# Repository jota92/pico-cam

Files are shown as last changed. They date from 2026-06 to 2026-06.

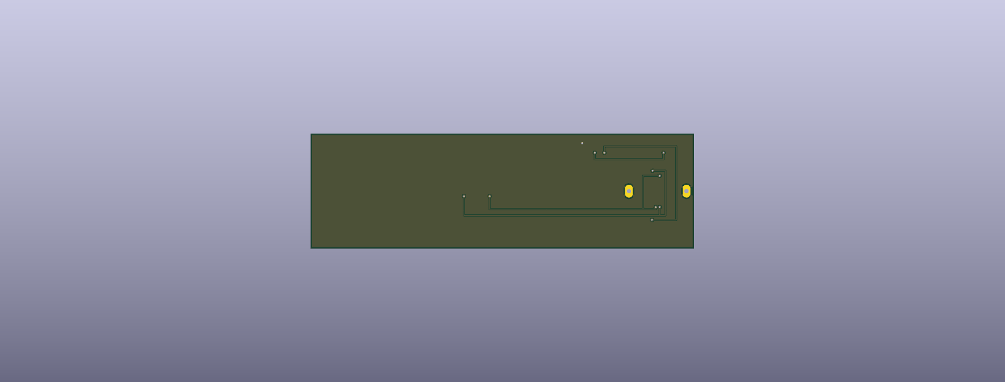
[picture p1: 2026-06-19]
pico-cam-latest/device_kicad/CameraIoT_USB-C_Programmer_Dock_bottom.png

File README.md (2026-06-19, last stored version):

# Pico-Cam (Camera IoT)

ESP32-S3 (ESP32-S3-PICO-1-N8R8) をベースにした、超小型・低消費電力の IoT カメラプロジェクトです。ディープスリープを活用し、定期的に JPEG 画像を撮影して Wi-Fi 経由でサーバーにアップロードします。

本リポジトリには、デバイス基板、書き込み・充電用のドック基板の KiCad 回路図・レイアウトデータ、PlatformIO 用のファームウェア、およびアップロード受信用サーバーのサンプルコードが含まれています。

---

## プロジェクト構成

```text
pico-cam/
├── camera_iot/                 # メインの開発・製造パッケージ
│   ├── device_kicad/           # デバイス本体の基板データ (38x18mm 版)
│   ├── cradle_kicad/           # 充電・書き込み用クレードル基板データ (RevA)
│   ├── mechanical/             # デバイスおよびクレードルのレイアウト画像・図面
│   ├── firmware_platformio/    # ESP32-S3 ファームウェア (PlatformIO)
│   ├── server_example/         # アップロード受信用 Express.js サーバー
│   ├── docs/                   # ピンマップや電気設計メモ、DRC レポートなどの設計文書
│   ├── scripts/                # 基板生成や監査用の各種 Python スクリプト
│   ├── jlcpcb_38x18/           # 38x18mm 版の製造用 Gerber/BOM/CPL 出力
│   └── jlcpcb_dock/            # ドック基板の製造用 Gerber/BOM/CPL 出力
├── device_kicad_friend/        # 代替・改良版の基板データ
│   ├── CameraIoT_RevF_40x20_ThroughVia_FINAL.kicad_pcb  # RevF 本体基板 (40x20mm、ブラインドビアなしの通常の4層)
│   ├── CameraIoT_USB-C_Programmer_Dock.kicad_pcb        # USB-C プログラマードック基板
│   └── README_HANDOFF.md       # RevF 基板の製造仕様・引き継ぎドキュメント
├── KiCad/                      # 実行環境用の KiCad 設定 / プロファイル
├── .kicad_cli_profile/         # KiCad CLI 用プロファイル
├── freerouting-1.9.0.jar       # 基板配線用オートルーター (FreeRouting)
└── README.md                   # 本ドキュメント
```

---

## ハードウェア仕様

本プロジェクトには、用途や製造コストに合わせて 2 つの基板バリエーションが存在します。

### 1. デバイス本体基板

*   **ESP32-S3-PICO-1-N8R8**: 8MB Quad Flash & 8MB Octal PSRAM 内蔵モジュール
*   **インターフェース**: カメラモジュール (OV2640 等)、充電検出、ステータス LED、操作ボタン
*   **電源**: LiPo バッテリー接続用コネクタ (J2: JST SH 2ピン)

#### バリエーション:
1.  **38x18mm 版 (`camera_iot/device_kicad/`)**:
    *   極小サイズの設計。
    *   製造用データは `camera_iot/jlcpcb_38x18/` にあります。
2.  **40x20mm RevF 版 (`device_kicad_friend/`)**:
    *   ブラインドビア/埋め込みビアを排除し、通常の「4層貫通ビア (Through-Via)」のみで配線した設計。
    *   JLCPCB などの一般的な基板メーカーで安価に製造可能。
    *   外形寸法: 40.0 x 20.0 mm、基板厚: 0.8 mm。

### 2. 充電・書き込み用ドック (クレードル)

デバイス本体には USB コネクタを搭載せず、外部ドック（ポゴピンまたはケーブル接続）を介して充電やファームウェア書き込みを行います。

*   **Pogo ピンまたは 6-Pin ケーブルインターフェース**:
    1.  `VBUS / VCHG_5V` (電源)
    2.  `GND` (グランド)
    3.  `USB_D+` (native USB D+ / GPIO20)
    4.  `USB_D-` (native USB D- / GPIO19)
    5.  `GPIO0 / BOOT` (書き込みモード遷移用)
    6.  `CHIP_PU / RESET` (チップリセット)
    *   (RevC の pogo 設計では、STAT / WAKE_ID を含めた 8 ポゴピン仕様も存在)

---

## ファームウェア (PlatformIO)

`camera_iot/firmware_platformio/` に格納されているファームウェアは、ESP32-S3 の native USB 機能と Wi-Fi 機能、省電力制御を実装しています。

### ピンアサイン (Pin Map)
*   **PSRAM 競合回避**: ESP32-S3-PICO-1-N8R8 は Octal PSRAM のために `GPIO33~37` を占有するため、カメラのデータラインを `GPIO10-14`、`GPIO38-40` にマッピングして競合を回避しています。
*   **主要ピン**:
    *   `PWDN_GPIO_NUM`: GPIO21
    *   `RESET_GPIO_NUM`: GPIO18
    *   `XCLK_GPIO_NUM`: GPIO15
    *   `SIOD_GPIO_NUM` (SDA): GPIO8
    *   `SIOC_GPIO_NUM` (SCL): GPIO9
    *   `Y2 ~ Y9` (カメラデータ D2~D9): GPIO40, 39, 38, 14, 13, 12, 11, 10
    *   `VSYNC_GPIO_NUM`: GPIO16
    *   `HREF_GPIO_NUM`: GPIO17
    *   `PCLK_GPIO_NUM`: GPIO41
    *   `LED_STATUS_GPIO`: GPIO47 (ステータス LED)
    *   `CHG_DETECT_GPIO`: GPIO4 (充電検出ピン、分圧経由)
    *   `WAKE_BUTTON_GPIO`: GPIO5 (操作・スリープ解除ボタン)
    *   `WAKE_ID_GPIO`: GPIO1 (クレードル接続識別)
    *   `USB_DN_GPIO / USB_DP_GPIO`: GPIO19 / GPIO20 (Native USB デバッグ・書き込み用)

### 主な動作フロー:
1.  **起動**: スリープまたは電源 ON で起動。
2.  **充電検出**: `CHG_DETECT_GPIO` が HIGH の場合（ドックで充電中など）、不要なカメラ撮影や Wi-Fi 接続を行わず、充電に専念するために即座に 1 分間のディープスリープに入ります。
3.  **撮影**: カメラを初期化し、JPEG 画像を取得して PSRAM に格納。
4.  **Wi-Fi 送信**: Wi-Fi に接続し、指定された HTTP サーバへ POST リクエストで画像を送信。
5.  **休止**: 送信完了（またはタイムアウト/エラー）後、ステータス LED をパターン点滅させ、10 分間のディープスリープに入ります。

---

## サーバー (server_example)

`camera_iot/server_example/` は Node.js (Express.js) で書かれたシンプルなアップロード受付サーバーです。

*   **動作**: 送信されてきた Raw JPEG データをトークン認証の上で受信し、日時とランダム文字列のファイル名（例: `2026-06-20T01-23-57-123Z-abcd1234.jpg`）で `./uploads` ディレクトリに保存します。
*   **起動方法**:
    ```bash
    cd camera_iot/server_example
    npm install
    # トークンやポートを指定して起動
    PORT=3000 DEVICE_TOKEN="your-secret-token" node server.js
    ```

---

## 開発と製造に関する注意点

*   **BOM の手配**: LCSC などの自動 PCBA を利用する場合、カメラコネクタや一部の IC など、手作業でのマウント (PCBA 後の手半田) が必要な部品が存在します。詳細は `camera_iot/docs/manual_procurement_revC.md` や `device_kicad_friend/README_HANDOFF.md` をご確認ください。
*   **DRC（デザインルールチェック）**:
    *   RevF 基板は KiCad 10.0.1 の DRC にて、重大なエラー・未配線ともに 0 件であることを確認済みです。

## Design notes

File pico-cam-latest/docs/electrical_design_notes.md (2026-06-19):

# Electrical Design Notes

## Current architecture

- Device board: `40 x 20 mm`, 4-layer, `0.8 mm`
- Dock board: USB-C to 6-wire cable dock, 2-layer, `1.0 mm`
- No pogo pins
- Device charging/programming connector:
  - `J3 = JST SH SM06B-SRSS-TB(LF)(SN) / C160405`
- Battery connector:
  - `J2 = JST SH SM02B-SRSS-TB(LF)(SN) / C160402`

## 6-wire cable pinout

1. `VCHG_5V`
2. `GND`
3. `USB_D+`
4. `USB_D-`
5. `GPIO0`
6. `CHIP_PU`

## Device behavior assumptions

- Charging input is detected by `CHG_DETECT` divider on `GPIO4`
- User button is on `GPIO5`
- Status LED is on `GPIO47`
- Native USB uses `GPIO19/GPIO20`
- `GPIO0` and `CHIP_PU` are exported only to the dock connector for flashing/reset

## Stock-driven substitutions applied

- `R1` charge-program resistor: `20k -> 21k`
- `R2/R9` divider and button pull-up: `100k -> 110k`
- `R4/R5/R6/R7`: `10k -> 12.4k`
- `R10`: `33R -> 30.1R`
- `R3/R11/R12/L2`: moved to `RTT029310FTH / C11715`
- Cradle CC resistors: `5.1k -> 5.11k`
- Removed cradle LEDs and their resistors
- Removed large 47uF output capacitor; output bulk now relies on distributed 10uF network already placed around `3V3`

## Known procurement caveats

- `U1`, `U5`, `LED1` are not closed by the current LCSC-only BOM and remain consign/global-sourcing candidates
- All other changed JST and passive parts were selected from currently in-stock LCSC alternatives during this revision

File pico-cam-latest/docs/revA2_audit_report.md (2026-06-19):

# CameraIoT RevA2 correction report

This package fixes the RevA1 fatal inconsistencies.

## Fixed

- ESP32-S3-PICO-1-N8R8 U1 pad net assignment now follows the Espressif package pin numbers.
- Camera D9-D5 are assigned to GPIO10-GPIO14 / U1 pads 15-19.
- U1 pads 38-42, which correspond to GPIO33-GPIO37, are left unconnected because they are used by the N8R8 octal PSRAM.
- CAM_D2 is no longer connected to U1 pad46. U1 pad46 is now 3V3 because it is VDD3P3_CPU.
- U1 pads55/56 are now 3V3 because they are VDDA. They were incorrectly tied to GND in the previous placeholder footprint.
- UART programming pins are now U1 pad49/U0TXD and U1 pad50/U0RXD.
- LED_STATUS is now GPIO47 / U1 pad37.
- Device and cradle pogo pitch remains 4.0 mm: 5V/GND/STAT/WAKE.
- Power, charger, LDO, RF matching, pullups, divider, LED, and passives now have explicit nets.

## Important remaining manufacturing note

This package corrects pad/net assignment. It still must be opened in KiCad and fully routed, DRC/ERC checked, and exported to Gerber before JLCPCB ordering. Do not upload the KiCad PCB directly as a finished production design without routing/DRC.

## Files added

- docs/device_pad_net_assignment_revA2.csv
- docs/cradle_pad_net_assignment_revA2.csv
- docs/revA2_audit_report.md
- docs/revA2_validation_report.txt

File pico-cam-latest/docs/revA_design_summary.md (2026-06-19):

# RevA1 design summary

Smallest version that still has a reasonable chance to boot, capture JPEG, send via Wi-Fi, and
charge via pogo pins. RevA1 applies the design-review fixes listed in FIXES_RevA1.md.

## What changed from earlier concept

- Camera DOVDD is 2.8 V (not 3.3 V) to match OV2640FSL typical module design.
- Added 2.8 V and 1.3 V LDOs; the camera cannot be powered from 3.3 V only.
- Added bottom programming pads because the final body has no USB-C.
- Battery is bottom-side adhesive/manual assembly, not JLC SMT.
- Antenna is fully inside the 40 x 20 mm outline, chip antenna + keepout.

## RevA1 fixes (key)

- Camera D9..D5 moved off GPIO33-37 (octal-PSRAM pins) -> GPIO10..14.
- Device charge-pad pitch set to 4.0 mm to match the cradle pogo pitch.
- 5V-detect divider re-ratioed (68k/100k -> ~3.0 V) off the logic threshold.
- GND reference zones + narrowed antenna keepout for RF.
- Added ESP32 local decoupling (0.1 uF x2 + 10 uF).
- Battery spec changed to PROTECTED cell; battery area cleared from antenna keepout.
- Cradle gets the charge LED (driven by STAT); redundant device charge LED removed.
- firmware memory_type corrected to qio_opi for N8R8.

## Remaining one-shot risk areas (verify before order)

- ESP32-S3-PICO-1 LGA56 land pattern + pin-1 must be rebuilt from the official Espressif
  drawing. The placeholder footprint's pad-to-function mapping is NOT the real pinout.
- OV2640 FPC connector orientation/contact side must be verified with a real camera module.
- RF match is not guaranteed until VNA tuning in the real case.
- Z-stack: camera (top) over battery (bottom) can reach ~11.85 mm if they overlap in XY.
  Use a <=3.2 mm cell under the camera footprint, a local battery cutout, or push the camera
  fully into the corner so it does not sit over the battery.
- 401230 high-discharge PROTECTED cell; common 1C cells are not enough for Wi-Fi peaks.
- All LCSC/JLC part numbers must be filled before a PCBA order (left blank intentionally).

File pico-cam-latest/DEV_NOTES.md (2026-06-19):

# Camera IoT RevC fabrication package

2026-06-16 時点で、RevC の completed routed 版を再構築済みです。  
ただし、この環境では `kicad-cli pcb drc` が異常終了するため、
最終確認は `導通監査 + 局所電源/インターフェース検証 + Gerber再生成` で行っています。

同日付で、新仕様として以下も追加しています。

- 本体ボタン 1 個で `短押し撮影 / 3秒 BLE設定 / 10秒 初期化`
- ステータス LED
- BLE 初期設定前提の `WAKE_ID` 分離
- 充電・書き込みドック用の **8 pogo** (`VBUS/GND/D+/D-/BOOT/RESET/STAT/WAKE_ID`)
- ESP32-S3 native USB (`GPIO19/20`) を使うドック経由書き込み

旧 `RevA*` 一式は監査・修正履歴として残していますが、発注入力には使わないでください。

## 完成物

- デバイス基板: `production_revC/device/CameraIoT_RevC_routed.kicad_pcb`
- クレードル基板: `production_revC/cradle/USB_C_to_Pogo_Cradle_RevC_routed.kicad_pcb`
- JLCPCB 用データ:
  - `production_revC/jlcpcb/device_BOM_JLCPCB_RevC.csv`
  - `production_revC/jlcpcb/device_CPL_JLCPCB_RevC.csv`
  - `production_revC/jlcpcb/device_manual_post_pcba_parts_RevC.csv`
  - `production_revC/jlcpcb/cradle_BOM_JLCPCB_RevC.csv`
  - `production_revC/jlcpcb/cradle_CPL_JLCPCB_RevC.csv`
  - `production_revC/jlcpcb/cradle_manual_post_pcba_parts_RevC.csv`
- Gerber ZIP:
  - `production_revC/device/CameraIoT_RevC_Gerbers.zip`
  - `production_revC/cradle/USB_C_to_Pogo_Cradle_RevC_Gerbers.zip`

## 現在の状態

- デバイス基板:
  - `scripts/build_device_revC_routed.py` で `CameraIoT_RevC_routed.kicad_pcb` を再生成可能
  - `scripts/check_revC_power_cell.py` は routed 完成版で `PASS`
  - `scripts/check_revC_interface_spec.py` は routed 完成版で `PASS`
  - `scripts/audit_connectivity.py` は routed 完成版で `unconnected_edges=0`
- クレードル基板:
  - 新仕様で USB2 D+/D- と 8 pogo、FLASH/RESET ボタンを追加
  - `scripts/audit_connectivity.py` では routed 完成版の `unconnected_edges=0` を確認済み
  - pogo は `Mill-Max 0906-0-15-20-75-14-11-0` を採用し、手実装前提で固定
- クレードルの手差しポゴピンは BOM から除外済み
- デバイスは `J2` LiPo SMT コネクタを追加済みで、電池リードの基板直半田は不要
- デバイスの底面接点とテストパッドは手作業項目として分離済み

## 発注時の注意

- `device_BOM_JLCPCB_RevC.csv` には LCSC 空欄が 9 行あります。これらは
  `JLC global sourcing/consigned` 前提です。
- カメラモジュール、電池、クレードルのポゴピンは PCBA 後の手組みです。
- 電池と pogo の固定品番は `docs/manual_procurement_revC.md` を見てください。
- KiCad 純正 DRC レポートだけは、この環境で `kicad-cli` が exit 134 になるため未取得です。

## 生成スクリプト

- RevC 生成元: `scripts/generate_revC.py`
- routed device 再構築: `scripts/build_device_revC_routed.py`
- 局所検証: `scripts/check_revC_power_cell.py`
- I/O仕様検証: `scripts/check_revC_interface_spec.py`
- 導通監査: `scripts/audit_connectivity.py`
- fabrication 出力再生成: `scripts/export_revC_fab.py`
- 旧 routed 基板局所修復: `scripts/repair_revC_routed_board.py`

KiCad 付属 Python で再生成する場合:

```bash
HOME=/tmp/kicad-home KICAD_CONFIG_HOME=/tmp/kicad-config \
/tmp/KiCad.app/Contents/Frameworks/Python.framework/Versions/3.9/bin/python3 \
scripts/generate_revC.py
```

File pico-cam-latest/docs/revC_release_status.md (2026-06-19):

# RevC Release Status

最終更新: 2026-06-17

## 結論

RevC は `pogo` を廃止し、6線 JST-SH ケーブル経由の USB-C ドック構成へ更新済みです。

- 本体: `production_revC/device/CameraIoT_RevC_routed.kicad_pcb`
- ドック: `production_revC/cradle/USB_C_to_Cable_Dock_RevC_routed.kicad_pcb`
- Gerber:
  - `production_revC/device/CameraIoT_RevC_Gerbers.zip`
  - `production_revC/cradle/USB_C_to_Cable_Dock_RevC_Gerbers.zip`

## 確認済み

- `scripts/check_revC_interface_spec.py`:
  - 6線ケーブル割当 `VCHG_5V / GND / USB_D+ / USB_D- / GPIO0 / CHIP_PU` を確認
- `scripts/audit_connectivity.py`:
  - device routed: `split_nets none`
  - cradle routed: `split_nets none`
- TPS63031 ピン割当は修正済み
- バッテリコネクタは LCSC 在庫ありの `SM02B-SRSS-TB(LF)(SN) / C160402` に変更済み
- ドック/本体ケーブルコネクタは `SM06B-SRSS-TB(LF)(SN) / C160405` に変更済み
- クレードル CC 抵抗は `5.11k / C25904` へ変更済み

## BOM 上の注意

以下は BOM 上で `consign` 扱いです。

- `U1` ESP32-S3-PICO-1-N8R8
- `U5` TLV70013DDCR
- `LED1` XL-1608UBC

つまり、**Gerber/BOM/CPL は生成済みだが、全点が LCSC 通常在庫だけで閉じているわけではありません。**
JLCPCB へはそのまま提出可能ですが、上記 3 点は JLC 側の実装可否確認または consign/global sourcing 前提です。

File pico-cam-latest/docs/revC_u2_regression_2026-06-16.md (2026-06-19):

# RevC U2 regression audit (2026-06-16)

## 要約

RevC デバイス基板は実際に配線済みで、既存 DRC レポートも `0 violations / 0 unconnected`
でした。  
ただし再監査で、`U2` TPS63031 のネット割当が生成スクリプトで回帰していることを確認しました。

これは **DRC では見抜けない論理結線ミス** です。  
したがって、既存の routed 基板と Gerber は現時点では発注不可です。

## 原因

`scripts/generate_revC.py` の旧実装:

```python
u2_nets = ["3V3", "SW2", "GND", "SW1", "VBAT", "VBAT", "GND", "VBAT", "GND", "3V3"]
```

この割当は TPS63031DSKR の正規 DSK ピン配置と一致しません。

正しい割当:

```python
u2_nets = ["SW1", "VBAT", "VBAT", "VBAT", "GND", "GND", "SW2", "3V3", "GND", "GND"]
```

## 影響

- `U2` 周辺の routed デバイス基板配線は、誤ったネット前提で成立している
- 既存 `production_revC/device/CameraIoT_RevC.kicad_pcb` は再ルーティングが必要
- 既存 Gerber / BOM / CPL / 発注用コピーは、そのまま使えない

## 補足

- `docs/recheck_2026-06-15_device_drc.txt`
- `docs/recheck_2026-06-15_cradle_drc.txt`

これらは RevC ではなく、旧 RevA 配置ファイルに対する再確認レポートです。
RevC の routed 基板評価と混同しないこと。

## 現在の対処

- 生成スクリプトの `U2` ネット割当は修正済み
- `U2` 周辺の固定配線と部品配置も修正済み
- `scripts/check_revC_power_cell.py` を追加し、以下をローカル再検証可能にした
  - `U2` pad1-11 のネット割当
  - `C4/C5/C7/C17/R8/R9/L1/U2` の局所配置
  - `SW1/SW2/VBAT/3V3` の固定配線
  - 電源セル局所クリアランス
- このチェッカーは `CameraIoT_RevC_unrouted.kicad_pcb` では通過し、
  既存 `CameraIoT_RevC.kicad_pcb` では失敗する
- `scripts/repair_revC_routed_board.py` で routed 基板の局所修復版
  `CameraIoT_RevC_repaired_local.kicad_pcb` を生成可能で、これも局所チェッカーを通過する
- ただし、修正後の routed デバイス基板は未再認定
- クレードル基板は今回の回帰の直接対象外

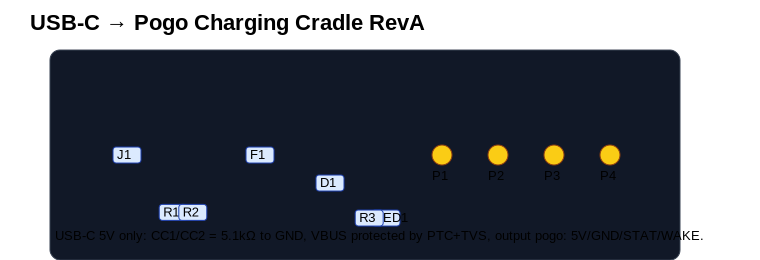
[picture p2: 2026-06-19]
pico-cam-latest/mechanical/cradle_layout_revA.png

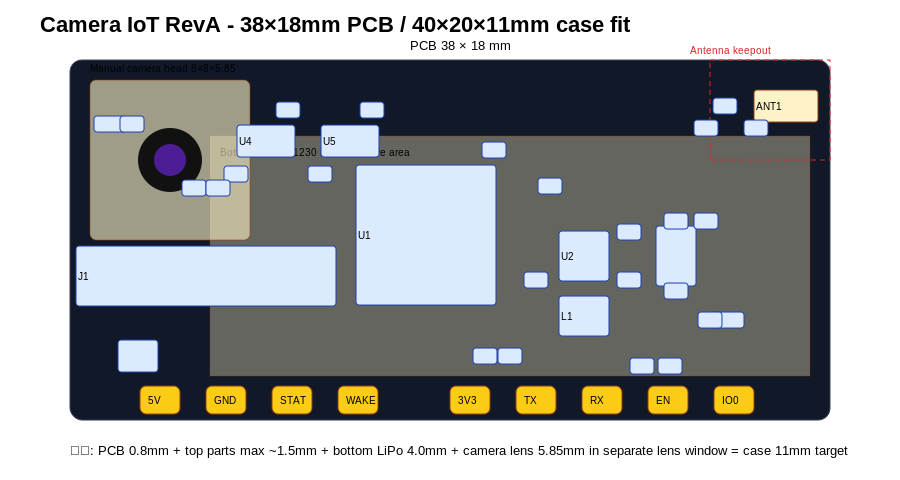
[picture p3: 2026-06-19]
pico-cam-latest/mechanical/device_layout_revA.png

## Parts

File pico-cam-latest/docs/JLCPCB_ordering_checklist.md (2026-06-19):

# JLCPCB Ordering Checklist

## 提出ファイル

本体:

1. `production_revC/device/CameraIoT_RevC_Gerbers.zip`
2. `production_revC/jlcpcb/device_BOM_JLCPCB_RevC.csv`
3. `production_revC/jlcpcb/device_CPL_JLCPCB_RevC.csv`

ドック:

1. `production_revC/cradle/USB_C_to_Cable_Dock_RevC_Gerbers.zip`
2. `production_revC/jlcpcb/cradle_BOM_JLCPCB_RevC.csv`
3. `production_revC/jlcpcb/cradle_CPL_JLCPCB_RevC.csv`

補助:

- `production_revC/jlcpcb/device_manual_post_pcba_parts_RevC.csv`
- `production_revC/jlcpcb/cradle_manual_post_pcba_parts_RevC.csv`

## 実装前提

- 本体は 4 層 0.8 mm
- ドックは 2 層 1.0 mm
- pogo は廃止済み
- 本体とドックの接続は `JST SH 6-pin (SM06B-SRSS-TB)` ケーブル

## ドック配線仕様

1. `pin1 = VCHG_5V`
2. `pin2 = GND`
3. `pin3 = USB_D+`
4. `pin4 = USB_D-`
5. `pin5 = GPIO0 / FLASH`
6. `pin6 = CHIP_PU / RESET`

## 発注時の注意

- `U1`, `U5`, `LED1` は BOM 上 consign 扱い
- それ以外の置換済み受動部品と JST コネクタは、2026-06-17 時点で LCSC 在庫確認済み
- 本体の `TP1/TP2/TP3` は銅パッドで、追加部品実装は不要

## 最終確認コマンド

```bash
/private/tmp/KiCad.app/Contents/Frameworks/Python.framework/Versions/3.9/bin/python3 scripts/check_revC_interface_spec.py production_revC/device/CameraIoT_RevC_routed.kicad_pcb production_revC/cradle/USB_C_to_Cable_Dock_RevC_routed.kicad_pcb
/private/tmp/KiCad.app/Contents/Frameworks/Python.framework/Versions/3.9/bin/python3 scripts/audit_connectivity.py production_revC/device/CameraIoT_RevC_routed.kicad_pcb production_revC/cradle/USB_C_to_Cable_Dock_RevC_routed.kicad_pcb
```

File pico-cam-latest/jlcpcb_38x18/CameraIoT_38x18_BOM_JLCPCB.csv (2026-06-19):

Comment | Designator | Footprint | Manufacturer | Manufacturer Part Number | LCSC Part # | Quantity | Notes
2.4GHz chip antenna | ANT1 | ANT_2450AT18B100E | Johanson Technology | 2450AT18B100E | C2917717 | 1 | JLCPCB SMT
10uF | C10,C16,C8 | C_0603_1608Metric | Samsung | CL10A106MQ8NNNC | C19702 | 3 | JLCPCB SMT
4.7uF | C11,C9 | C_0603_1608Metric | Samsung | CL10A475KO8NNNC | C19666 | 2 | JLCPCB SMT
1uF | C12,C13,C3 | C_0402_1005Metric | Samsung | CL05A105KA5NQNC | C52923 | 3 | JLCPCB SMT
0.1uF | C14,C15,C17 | C_0402_1005Metric | Samsung | CL05B104KO5NNNC | C1525 | 3 | JLCPCB SMT
10uF 6.3V | C4,C5,C6 | C_0603_1608Metric | Samsung | CL10A106MQ8NNNC | C19702 | 3 | JLCPCB SMT
47uF 6.3V | C7 | C_1206_3216Metric | Samsung | CL31A476MQHNNNE | C2013 | 1 | JLCPCB SMT
OV2640 24pin FPC | J1 | FPC_24P_0.5mm_Molex52437-2491 | Molex | 52437-2471 | C3169564 | 1 | JLCPCB SMT
USB-C power+USB2 | J2 | CameraIoT_USB-C-16P |  | TYPE-C-31-M-12 | C165948 | 1 | JLCPCB SMT
1.5uH >=1.5A | L1 | IND_2520 | Murata | DFE252012F-1R5M=P2 | C909806 | 1 | JLCPCB SMT
0R/DNP RF series | L2 | R_0402_1005Metric | UNI-ROYAL | 0402WGF0000TCE | C17168 | 1 | JLCPCB SMT
Blue status LED | LED1 | LED_0603_1608Metric | Everlight | 19-21/BHC-ZL1M2VY/3T | C2290 | 1 | JLCPCB SMT
20k 1% | R1 | R_0402_1005Metric | UNI-ROYAL | 0402WGF2002TCE | C25741 | 1 | JLCPCB SMT
5.11k CC1 | R10 | R_0402 | UNI-ROYAL | 0402WGF1001TCE | C21190 | 1 | JLCPCB SMT
5.11k CC2 | R11 | R_0402 | UNI-ROYAL | 0402WGF1001TCE | C21190 | 1 | JLCPCB SMT
1k | R3 | R_0402_1005Metric | UNI-ROYAL | 0402WGF1001TCE | C21190 | 1 | JLCPCB SMT
10k | R4,R5,R6,R7 | R_0402_1005Metric | UNI-ROYAL | 0402WGF1002TCE | C25744 | 4 | JLCPCB SMT
68k | R8 | R_0402_1005Metric | Yageo | RC0402FR-0768KL | C25907 | 1 | JLCPCB SMT
100k | R9 | R_0402_1005Metric | UNI-ROYAL | 0402WGF1003TCE | C25803 | 1 | JLCPCB SMT
Wake/Boot button | SW1 | SW_2x1.6mm | ALPS Alpine | SKRPACE010 | C139797 | 1 | JLCPCB SMT
ESP32-S3-PICO-1-N8R8 | U1 | LGA56_7x7mm_P0.4_PIN1TL | Espressif | ESP32-S3-PICO-1-N8R8 | C7545129 | 1 | JLC SMT/consign
3.3V buck-boost | U2 | VSON10_2.5x2.5_DSK | Texas Instruments | TPS63031DSKR | C15516 | 1 | JLCPCB SMT
LiPo charger 4.2V | U3 | SOT-23-5 | Microchip | MCP73831T-2ACI/OT | C424093 | 1 | JLCPCB SMT
2.8V LDO | U4 | SOT-23-5 | Texas Instruments | TLV70028DDCR | C507266 | 1 | JLCPCB SMT
1.3V LDO | U5 | SOT-23-5 | Texas Instruments | TLV70013DDCR | TLV70013DDCR | 1 | JLC SMT/consign

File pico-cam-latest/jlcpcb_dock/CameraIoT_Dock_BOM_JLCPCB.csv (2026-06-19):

Comment | Designator | Footprint | Manufacturer | Manufacturer Part Number | LCSC Part # | Quantity | Notes
5V TVS | D1 | SOD-523 | TECH PUBLIC | ESD5Z5V0 | C302007 | 1 | JLCPCB SMT
500mA PTC | F1 | Fuse_1206 | Littelfuse | 1206L050/15YR | C70069 | 1 | JLCPCB SMT
USB-C power+USB2 | J1 | CameraIoT_USB-C-16P | G-Switch | TYPE-C-31-M-12 | C165948 | 1 | JLCPCB SMT
Power LED | LED1 | LED_0603 | Everlight | 19-217/GHC-YR1S2/3T | C72043 | 1 | JLCPCB SMT
Charge LED | LED2 | LED_0603 | Everlight | 19-217/R6C-AL1M2VY/3T | C72039 | 1 | JLCPCB SMT
5.1k | R1,R2 | R_0402 | Yageo | RC0402FR-075K1L | C25905 | 2 | JLCPCB SMT
2.2k | R3,R4 | R_0402 | Yageo | RC0402FR-072K2L | C25879 | 2 | JLCPCB SMT
FLASH button | SW2 | CameraIoT_SKRPACE010 | ALPS Alpine | SKRPACE010 | C139797 | 1 | JLCPCB SMT
RESET button | SW3 | CameraIoT_SKRPACE010 | ALPS Alpine | SKRPACE010 | C139797 | 1 | JLCPCB SMT

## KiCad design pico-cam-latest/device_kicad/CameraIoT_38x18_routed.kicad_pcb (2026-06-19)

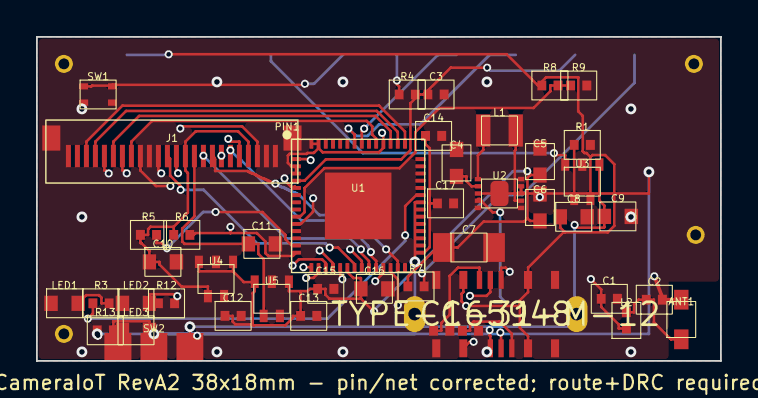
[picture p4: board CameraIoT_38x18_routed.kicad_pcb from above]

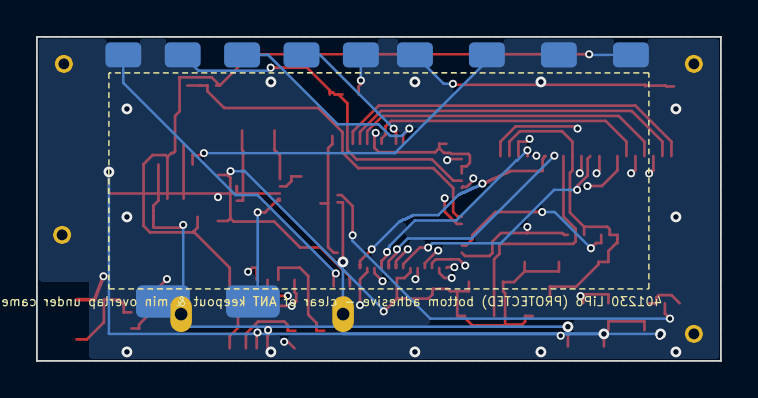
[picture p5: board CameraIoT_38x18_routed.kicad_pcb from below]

Board: 4 copper layers, 38.0 x 18.0 mm, 59 parts (11 on the bottom side), 45 nets.

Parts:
ANT1: 2.4GHz chip antenna; ANT_2450AT18B100E
BAT+: BAT+; BATP
BAT-: BAT-; BATN
C1, C2: DNP RF shunt; C_0402_1005Metric
C3, C12, C13: 1uF; C_0402_1005Metric
C4, C5, C6: 10uF 6.3V; C_0603_1608Metric
C7: 47uF 6.3V; C_1206_3216Metric
C8, C10, C16: 10uF; C_0603_1608Metric
C9, C11: 4.7uF; C_0603_1608Metric
C14, C15, C17: 0.1uF; C_0402_1005Metric
J1: OV2640 24pin FPC; FPC_24P_0.5mm_Molex52437-2491
J2: USB-C power+USB2; CameraIoT_USB-C-16P
L1: 1.5uH >=1.5A; IND_2520
L2: 0R/DNP RF series; R_0402_1005Metric
LED1: Blue status LED; LED_0603_1608Metric
LED2: Red Power LED; LED_0603_1608Metric
LED3: Green WiFi LED; LED_0603_1608Metric
MH1: MH1
MH2: MH2
MH3: MH3
MH4: MH4
R1: 20k 1%; R_0402_1005Metric
R3, R12, R13: 1k; R_0402_1005Metric
R4, R5, R6, R7: 10k; R_0402_1005Metric
R8: 68k; R_0402_1005Metric
R9: 100k; R_0402_1005Metric
R10: 5.11k CC1; R_0402
R11: 5.11k CC2; R_0402
SW1: Wake/Boot button; SW_2x1.6mm
SW2: Power Switch
TP1: 5V; BottomPad_5V
TP2: GND; BottomPad_GND
TP3: STAT; BottomPad_STAT
TP4: WAKE; BottomPad_WAKE
TP5: 3V3; BottomPad_3V3
TP6: TX; BottomPad_TX
TP7: RX; BottomPad_RX
TP8: EN; BottomPad_EN
TP9: IO0; BottomPad_IO0
U1: ESP32-S3-PICO-1-N8R8; LGA56_7x7mm_P0.4_PIN1TL
U2: 3.3V buck-boost; VSON10_2.5x2.5_DSK
U3: LiPo charger 4.2V; SOT-23-5
U4: 2.8V LDO; SOT-23-5
U5: 1.3V LDO; SOT-23-5

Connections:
1V3: C11.1, J1.10, U5.5
2V8: C10.1, J1.4, J1.11, R5.1, R6.1, U4.5
3V3: C5.1, C6.1, C7.1, C12.1, C13.1, C15.1, C16.1, R4.1, R7.1, R12.1, TP5.1, U1.2, U1.3, U1.20, U1.46, U1.55, U1.56, U2.8, U2.9, U4.1, U4.3, U5.1, U5.3
CAM_D2: J1.19, U1.45
CAM_D3: J1.21, U1.44
CAM_D4: J1.22, U1.43
CAM_D5: J1.20, U1.19
CAM_D6: J1.18, U1.18
CAM_D7: J1.16, U1.17
CAM_D8: J1.14, U1.16
CAM_D9: J1.12, U1.15
CAM_HREF: J1.9, U1.23
CAM_PCLK: J1.17, U1.47
CAM_PWDN: J1.8, U1.27
CAM_RESETB: J1.6, U1.24
CAM_SIOC: J1.5, R6.2, U1.14
CAM_SIOD: J1.3, R5.2, U1.13
CAM_VSYNC: J1.7, U1.22
CAM_XCLK: J1.13, U1.21
CC1: J2.A5, R10.1
CC2: J2.B5, R11.1
CHG_DETECT: R8.2, R9.1, U1.9
CHG_PROG: R1.1, U3.5
CHG_STAT: TP3.1, U3.1
CHIP_PU: C3.1, R4.2, TP8.1, U1.4
GND: ANT1.2, BAT-.1, C1.2, C2.2, C3.2, C4.2, C5.2, C6.2, C7.2, C8.2, C9.2, C10.2, C11.2, C12.2, C13.2, C14.2, C15.2, C16.2, C17.2, J1.2, J1.15, J1.S1, J1.S2, J2.A1, J2.A12, J2.B1, J2.B12, J2.S1, J2.S2, LED1.1, LED2.1, LED3.1, R1.2, R9.2, R10.2, R11.2, SW1.3, SW1.4, SW2.1, TP2.1, U1.57, U2.5, U2.6, U2.10, U2.11, U3.2, U4.2, U5.2
GPIO0: R7.2, TP9.1, U1.5
LED_A: LED1.2, R3.2
LED_PWR_A: LED2.2, R12.2
LED_STATUS: R3.1, U1.37
LED_WIFI: R13.1, U1.36
LED_WIFI_A: LED3.2, R13.2
LNA_IN: C1.1, L2.1, U1.1
RF_ANT: ANT1.1, C2.1, L2.2
TPS_EN: SW2.2, U2.3
TPS_L1: L1.1, U2.1
TPS_L2: L1.2, U2.7
U0RXD: TP7.1, U1.50
U0TXD: TP6.1, U1.49
USB_DN: J2.A7, J2.B7, U1.25
USB_DP: J2.A6, J2.B6, U1.26
VBAT: BAT+.1, C4.1, C9.1, SW2.3, U2.2, U2.4, U3.3
VCHG_5V: C8.1, J2.A4, J2.A9, J2.B4, J2.B9, R8.1, TP1.1, U3.4
VDD_SPI: C14.1, C17.1, U1.29
WAKE_BUTTON: SW1.1, SW1.2, TP4.1, U1.10

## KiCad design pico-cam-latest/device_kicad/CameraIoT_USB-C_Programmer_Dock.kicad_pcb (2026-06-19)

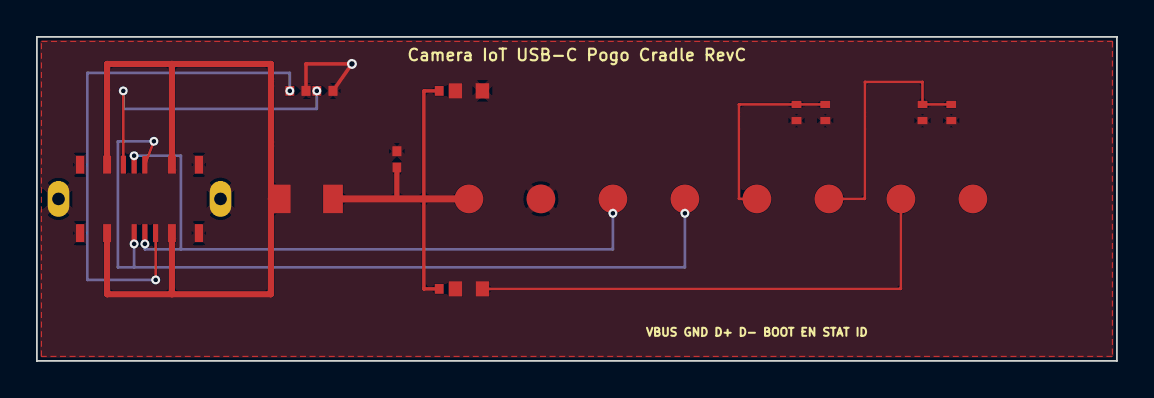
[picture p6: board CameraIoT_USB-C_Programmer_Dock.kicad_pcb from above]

Board: 2 copper layers, 60.0 x 18.0 mm, 19 parts (0 on the bottom side), 12 nets.

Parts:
D1: 5V TVS; SOD-523
F1: 500mA PTC; Fuse_1206
J1: USB-C power+USB2; CameraIoT_USB-C-16P
LED1: Power LED; LED_0603
LED2: Charge LED; LED_0603
P1: Pogo VBUS; CameraIoT_PogoPad_1.6
P2: Pogo GND; CameraIoT_PogoPad_1.6
P3: Pogo D+; CameraIoT_PogoPad_1.6
P4: Pogo D-; CameraIoT_PogoPad_1.6
P5: Pogo BOOT; CameraIoT_PogoPad_1.6
P6: Pogo RESET; CameraIoT_PogoPad_1.6
P7: Pogo STAT; CameraIoT_PogoPad_1.6
P8: Pogo WAKE/ID; CameraIoT_PogoPad_1.6
R1, R2: 5.1k; R_0402
R3, R4: 2.2k; R_0402
SW2: FLASH button; CameraIoT_SKRPACE010
SW3: RESET button; CameraIoT_SKRPACE010

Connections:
CC1: J1.A5, R1.1
CC2: J1.B5, R2.1
CHG_LED_A: LED2.1, R4.2
CHIP_PU: P6.1, SW3.1, SW3.2
GND: D1.2, J1.A1, J1.A12, J1.B1, J1.B12, J1.S1, J1.S2, LED1.2, P2.1, R1.2, R2.2, SW2.3, SW2.4, SW3.3, SW3.4
GPIO0: P5.1, SW2.1, SW2.2
PWR_LED: LED1.1, R3.2
STAT: LED2.2, P7.1
USB_DN: J1.A7, J1.B7, P4.1
USB_DP: J1.A6, J1.B6, P3.1
VBUS_5V: F1.1, J1.A4, J1.A9, J1.B4, J1.B9
VBUS_PROTECTED: D1.1, F1.2, P1.1, R3.1, R4.1

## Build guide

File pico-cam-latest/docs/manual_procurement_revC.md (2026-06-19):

# RevC manual / off-board procurement

この文書は、JLCPCB PCBA の外で調達・手組みする部品を固定するためのメモです。

## Cradle pogo

- Qty: 8
- MPN: `0906-0-15-20-75-14-11-0`
- Manufacturer: Mill-Max
- 用途: クレードル側 8 接点スプリングプローブ
- 実装前提: **手実装**

本 RevC では、この型番をクレードル側の実部品として固定します。  
JLCPCB の通常 PCBA にこの部品をそのまま載せられることは本環境では確認できていないため、
発注上は手実装前提です。

## Device battery connector

- PCB side connector `J2`
- MPN: `BM02B-SRSS-TB(LF)(SN)`
- Manufacturer: JST
- Series: SH, 2-pin, 1.0 mm pitch

### Mating parts

- Housing: `SHR-02V-S-B`
- Crimp terminal: `SSH-003T-P0.2`

## Battery pack

バッテリーセル自体は JLCPCB 実装対象ではありません。  
この設計で固定しているのは、**電気仕様・外形クラス・コネクタ系**です。

### Required battery spec

- 1S LiPo
- nominal `3.7 V`
- **PCM/protected cell required**
- size class: `401230`
- target capacity: `100-120 mAh`
- leadout: JST SH 2-pin mate
- polarity:
  - pin 1 = `VBAT` = red
  - pin 2 = `GND` = black

### Procurement note

この RevC は、特定の 1 SKU の市販電池に固定しないようにしています。  
理由は、保護回路有無、リード長、コネクタ向きの差が大きく、量産時に電池ベンダ変更が起こりやすいためです。

したがって、実調達は次のどちらかにしてください。

1. 上記仕様の完成品バッテリーパックを購入する
2. `401230 protected cell + JST SH mate` のカスタムリード品を作る

設計上の固定点は `J2 = BM02B-SRSS-TB(LF)(SN)` です。

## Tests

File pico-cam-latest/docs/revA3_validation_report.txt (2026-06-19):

RevA3 validation report (script-checked)
========================================
PASS  U1 pad-net vs official ESP32-S3-PICO-1 Table 2-1: 57/57 correct.
PASS  U1 geometry anti-clockwise, PIN1 top-left (1-14 L, 15-28 B, 29-42 R, 43-56 T, 57 C).
PASS  GPIO33-37 (pad38-42) and SPICS1 (pad28) left NC for octal PSRAM.
PASS  VDD3P3_CPU(pad46)=3V3, VDDA(pad55/56)=3V3, GND(pad57).
PASS  TPS63031 U2 pinout matches TI DSK (EN=VBAT, PS/SYNC=GND, FB=GND).
PASS  MCP73831 U3 and TLV70028/70013 U4/U5 pinouts match datasheets.
PASS  Cradle pogos single-pad, no GND short; P1=5V P2=GND P3=STAT P4=WAKE.
PASS  Cradle charge LED in series (VBUS->R4->CHG_LED_A->LED2->STAT).
PASS  USB-C J1 exposes VBUS/GND/CC1/CC2 with correct sink Rd.
PASS  Device/cradle pogo pitch 4.0 mm.
PASS  BOM/CPL regenerated from PCB; consistent designators.

NOT CHECKED HERE (must be done in KiCad before fabrication):
- Full routing, ERC, DRC, copper pours continuity.
- Final footprint land-pattern accuracy vs manufacturer drawings (esp. U1).
- LCSC part numbers (blank by design).
- RF tuning / power integrity / thermal.

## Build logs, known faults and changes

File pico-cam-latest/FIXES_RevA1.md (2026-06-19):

# FIXES applied in RevA1

Result of the RevA design review. Severity: [CRIT] won't work, [MAJ] reliability, [DOC] consistency.

## [CRIT] 1. Camera data bus collided with octal PSRAM
ESP32-S3-PICO-1-N8R8 uses octal PSRAM; on any ESP32-S3R8, GPIO33-37 are wired to the PSRAM and
must not be used. Camera D9..D5 were on GPIO33..37.
FIX: D9..D5 -> GPIO10..14 (D4..D2 stay 38/39/40). Updated pin_map, netlist, BOM-notes, firmware.
Firmware memory_type also corrected opi_opi -> qio_opi (N8R8 flash is quad, PSRAM is octal).

## [CRIT] 2. Pogo pitch mismatch (device vs cradle)
Device charge pads were 3.3 mm pitch; cradle pogos 4.0 mm -> pins 3 and 4 would miss the pads.
FIX: device charge pads moved to 4.0 mm pitch (5V=5.0, GND=9.0, STAT=13.0, WAKE=17.0).
Cradle pogos already 4.0 mm. Note added: confirm the mirror/order for the actual dock orientation.

## [MAJ] 3. 5V-detect divider sat on the logic threshold
100k/100k = 2.5 V ~= ESP32-S3 VIH (2.48 V) -> could read LOW under tolerance.
FIX: R8 100k -> 68k. Vdet = 5*100/(68+100) = 2.98 V.

## [MAJ] 4. No RF reference plane / over-broad antenna keepout
FIX: added solid GND zones (F.Cu, In1.Cu, B.Cu). Antenna keepout narrowed to the radiator only
(35.0-38.0 x 13.5-18.0) so the pi-match stays over ground. Keep the feed short when routing.

## [MAJ] 5. Battery fouled the antenna keepout (and camera Z-stack)
FIX: battery adhesive area moved to (4.0,2.0)-(34.0,14.0), clear of the antenna keepout.
Camera-over-battery worst-case Z (~11.85 mm) documented in mechanical_fit + summary - still must
be resolved mechanically (thin/short cell under the camera or a battery cutout).

## [MAJ] 6. Unprotected LiPo + no system UVLO
TPS63031 UVLO is far below LiPo-safe 3.0 V. FIX: battery spec changed to PROTECTED (PCM) cell;
production option to add a 3.0 V load switch noted.

## [MAJ] 7. Thin ESP32 decoupling
FIX: added C14/C15 (0.1 uF) + C16 (10 uF) close to the ESP32 3V3 pins.

## [DOC] 8. Charge LED location
Report wanted the charge LED on the cradle. FIX: charge LED (LED2 + R4) added to the cradle,
driven by the STAT pogo; the redundant in-case device charge LED (LED2/R2) was removed.

## [DOC] 9. Antenna / USB-C naming
Package standardized on antenna 2450AT18B100E (match its footprint+keepout) and cradle
USB4105-GF-A 16P (matches the 16P footprint; USB4125-GF-A 6P is an alternative).

## NOT auto-fixed (require your action before ordering) — see JLCPCB_ordering_checklist.md
- Fill all LCSC/JLC part numbers (left blank; do not guess).
- Rebuild the ESP32-S3-PICO-1 LGA56 footprint from the official Espressif drawing and map nets
  to the real pin functions (placeholder footprint).
- Build schematic, ERC, route, DRC, JLCPCB preview, VNA antenna tuning.

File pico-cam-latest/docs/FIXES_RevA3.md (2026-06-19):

# FIXES applied in RevA3

RevA3 closes the issues found when auditing RevA2 against the official ESP32-S3-PICO-1
datasheet (Table 2-1) and the TI/USB-C datasheets. All checks below were re-verified in script.

## [CRIT] U1 footprint physical geometry rebuilt to the real LGA56 layout
RevA2 had the correct net<->pad-number mapping, but the placeholder land placed the pads
clockwise (pads 1-14 on the top edge). The official ESP32-S3-PICO-1 LGA56 is numbered
ANTI-CLOCKWISE from pin 1 (top-left): pins 1-14 left edge, 15-28 bottom, 29-42 right,
43-56 top, 57 = center GND. The footprint pads were repositioned to match, with a PIN1
marker at top-left. Net<->pin-number remains 57/57 correct (re-verified vs datasheet).
Because nets are bound to pad NUMBERS, swapping in Espressif's official library footprint
keeps every connection correct.

## [CRIT] Cradle pogo footprints no longer short to GND
RevA2 modeled each pogo as TWO pads with pad2 tied to GND, which shorted 5V (P1), STAT (P3)
and WAKE (P4) to ground. Each pogo is now a SINGLE pad on its own net:
P1=VBUS_PROTECTED, P2=GND, P3=STAT, P4=WAKE_ID.

## [CRIT] TPS63031 (U2) pinout corrected to the real DSK package
RevA2 had an invented pin order. Now matches TI DSK: 1=L1, 2=VIN, 3=VINA, 4=EN, 5=PS/SYNC,
6=GND, 7=L2, 8=VOUT, 9=FB, 10=PGND, thermal=PGND. EN tied to VBAT (always enabled),
PS/SYNC tied to GND (power-save mode for low sleep current), FB tied to GND (fixed-output
3.3 V version), VOUT=3V3, VIN/VINA=VBAT, L1/L2 to the inductor.

## [MAJ] Cradle charge LED put in SERIES (was parallel)
RevA2 had R4 and LED2 both spanning VBUS_PROTECTED<->STAT (parallel, no current limit).
Now: VBUS_PROTECTED -> R4 -> CHG_LED_A -> LED2 -> STAT (series, limited).

## [MAJ] USB-C J1 rebuilt with real pads
RevA2 J1 had only 2 pads, so CC1/CC2 never reached the connector. J1 now uses the KiCad
USB_C_Receptacle_USB2.0_16P pad names: VBUS=A4/A9/B4/B9, GND=A1/A12/B1/B12+shield,
CC1=A5, CC2=B5 (Rd 5.1k on R1/R2), D+/-/SBU left NC (power-only cradle).

## [MIN] VDD_SPI decoupling added
C17 (0.1 uF) on U1 VDD_SPI (pin29) to GND.

## Verified by script in this build
- U1: 57/57 pad nets match datasheet; pads now anti-clockwise, PIN1 top-left.
- TPS63031, MCP73831, TLV70028/70013 pinouts all match their datasheets.
- No pogo GND shorts; charge LED is series; USB-C CC present.
- BOM/CPL regenerated directly from the PCB (no drift); TP*/MH*/BAT* excluded from SMT BOM.

## STILL required before ordering (workflow steps, cannot be pre-baked into this package)
1. Open in KiCad. Replace U1 (and verify all CUSTOM footprints: FPC 24P, pogo, antenna,
   USB-C, inductor) against the manufacturer's official land patterns. Nets are keyed to
   pad numbers/names, so official footprints drop in cleanly.
2. Route all nets, then run ERC and DRC until clean (the package is placement + connectivity,
   not finished copper; device has 2 stub segments, cradle 0).
3. Fill every LCSC/JLC part number in both BOMs (left blank on purpose - do not guess).
4. Export Gerbers; check the JLCPCB preview for component orientation and pin-1.
5. VNA-tune the antenna match (L2/C1/C2) in the assembled enclosure.

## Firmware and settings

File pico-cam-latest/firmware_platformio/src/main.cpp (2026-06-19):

#include <Arduino.h>
#include <WiFi.h>
#include <HTTPClient.h>
#include "esp_camera.h"

// CameraIoT RevC pin map.
// ESP32-S3-PICO-1-N8R8 reserves GPIO33-37 for octal PSRAM.
// GPIO19/20 are reserved for USB_D-/USB_D+ via the pogo cradle.
// The user button stays on GPIO5; cradle ID is split out to GPIO1.
#define PWDN_GPIO_NUM     21
#define RESET_GPIO_NUM    18
#define XCLK_GPIO_NUM     15
#define SIOD_GPIO_NUM      8
#define SIOC_GPIO_NUM      9
#define Y9_GPIO_NUM       10  // D9 MSB  (was 33 - PSRAM conflict)
#define Y8_GPIO_NUM       11  //         (was 34 - PSRAM conflict)
#define Y7_GPIO_NUM       12  //         (was 35 - PSRAM conflict)
#define Y6_GPIO_NUM       13  //         (was 36 - PSRAM conflict)
#define Y5_GPIO_NUM       14  //         (was 37 - PSRAM conflict)
#define Y4_GPIO_NUM       38
#define Y3_GPIO_NUM       39
#define Y2_GPIO_NUM       40  // D2 LSB
#define VSYNC_GPIO_NUM    16
#define HREF_GPIO_NUM     17
#define PCLK_GPIO_NUM     41

#define LED_STATUS_GPIO   47
#define CHG_DETECT_GPIO    4
#define WAKE_BUTTON_GPIO   5
#define WAKE_ID_GPIO       1
#define USB_DN_GPIO       19
#define USB_DP_GPIO       20

// Fill these in before flashing.
static const char* WIFI_SSID = "YOUR_WIFI_SSID";
static const char* WIFI_PASS = "YOUR_WIFI_PASSWORD";
static const char* UPLOAD_URL = "https://your-server.example.com/upload";
static const char* DEVICE_TOKEN = "replace-with-device-token";

static void blink(int n) {
  pinMode(LED_STATUS_GPIO, OUTPUT);
  for (int i=0; i<n; ++i) { digitalWrite(LED_STATUS_GPIO, HIGH); delay(100); digitalWrite(LED_STATUS_GPIO, LOW); delay(100); }
}

static bool init_camera() {
  camera_config_t config;
  config.ledc_channel = LEDC_CHANNEL_0;
  config.ledc_timer = LEDC_TIMER_0;
  config.pin_d0 = Y2_GPIO_NUM;
  config.pin_d1 = Y3_GPIO_NUM;
  config.pin_d2 = Y4_GPIO_NUM;
  config.pin_d3 = Y5_GPIO_NUM;
  config.pin_d4 = Y6_GPIO_NUM;
  config.pin_d5 = Y7_GPIO_NUM;
  config.pin_d6 = Y8_GPIO_NUM;
  config.pin_d7 = Y9_GPIO_NUM;
  config.pin_xclk = XCLK_GPIO_NUM;
  config.pin_pclk = PCLK_GPIO_NUM;
  config.pin_vsync = VSYNC_GPIO_NUM;
  config.pin_href = HREF_GPIO_NUM;
  config.pin_sccb_sda = SIOD_GPIO_NUM;
  config.pin_sccb_scl = SIOC_GPIO_NUM;
  config.pin_pwdn = PWDN_GPIO_NUM;
  config.pin_reset = RESET_GPIO_NUM;
  config.xclk_freq_hz = 20000000;
  config.pixel_format = PIXFORMAT_JPEG;

  if (psramFound()) {
    config.frame_size = FRAMESIZE_SVGA;  // 800x600 first test. Lower to VGA/QVGA if unstable.
    config.jpeg_quality = 12;
    config.fb_count = 2;
    config.grab_mode = CAMERA_GRAB_LATEST;
  } else {
    config.frame_size = FRAMESIZE_VGA;
    config.jpeg_quality = 14;
    config.fb_count = 1;
    config.grab_mode = CAMERA_GRAB_WHEN_EMPTY;
  }
  config.fb_location = CAMERA_FB_IN_PSRAM;

  esp_err_t err = esp_camera_init(&config);
  if (err != ESP_OK) {
    Serial.printf("Camera init failed: 0x%x\n", err);
    return false;
  }
  sensor_t *s = esp_camera_sensor_get();
  if (s) {
    s->set_framesize(s, FRAMESIZE_VGA); // safer default for first boot
  }
  return true;
}

static bool connect_wifi() {
  WiFi.mode(WIFI_STA);
  WiFi.setSleep(false);
  WiFi.begin(WIFI_SSID, WIFI_PASS);
  uint32_t start = millis();
  while (WiFi.status() != WL_CONNECTED && millis() - start < 12000) {
    delay(200);
    Serial.print('.');
  }
  Serial.println();
  Serial.print("WiFi status: "); Serial.println(WiFi.status());
  return WiFi.status() == WL_CONNECTED;
}

static bool upload_jpeg(camera_fb_t* fb) {
  if (!fb) return false;
  HTTPClient http;
  http.begin(UPLOAD_URL);
  http.addHeader("Content-Type", "image/jpeg");
  http.addHeader("X-Device-Token", DEVICE_TOKEN);
  http.addHeader("X-Device-Name", "camera-iot-revA");
  int code = http.POST(fb->buf, fb->len);
  Serial.printf("HTTP code: %d, bytes: %u\n", code, fb->len);
  String resp = http.getString();
  Serial.println(resp);
  http.end();
  return code >= 200 && code < 300;
}

static void sleep_now() {
  digitalWrite(LED_STATUS_GPIO, LOW);
  WiFi.disconnect(true);
  WiFi.mode(WIFI_OFF);
  esp_sleep_enable_timer_wakeup(10ULL * 60ULL * 1000000ULL); // test: wake every 10 min
  esp_deep_sleep_start();
}

void setup() {
  pinMode(CHG_DETECT_GPIO, INPUT);
  pinMode(WAKE_BUTTON_GPIO, INPUT_PULLUP);
  pinMode(LED_STATUS_GPIO, OUTPUT);
  Serial.begin(115200);
  delay(300);
  Serial.println("CameraIoT RevA boot");

  // If sitting on charger, do not capture or use Wi-Fi. Leave charge current to MCP73831.
  if (digitalRead(CHG_DETECT_GPIO) == HIGH) {
    Serial.println("Charge detected, sleeping.");
    blink(1);
    esp_sleep_enable_timer_wakeup(60ULL * 1000000ULL);
    esp_deep_sleep_start();
  }

  blink(2);
  if (!init_camera()) { blink(5); sleep_now(); }
  camera_fb_t *fb = esp_camera_fb_get();
  if (!fb) { Serial.println("Camera capture failed"); blink(5); sleep_now(); }
  Serial.printf("Captured: %u bytes\n", fb->len);

  bool ok = false;
  if (connect_wifi()) ok = upload_jpeg(fb);
  esp_camera_fb_return(fb);
  blink(ok ? 3 : 6);
  sleep_now();
}

void loop() {}

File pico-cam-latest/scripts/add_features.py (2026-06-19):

#!/usr/bin/env python3
"""
Add missing features to CameraIoT_38x18_routed.kicad_pcb:

1. SW2 (SPDT slide switch) on TPS63031 EN pin for main power off
   - SW2.1 = GND  (slide OFF: EN→GND → TPS disabled → device OFF)
   - SW2.2 = TPS_EN (COM, connected to U2.3 which was VBAT=always-on)
   - SW2.3 = VBAT  (slide ON: EN→VBAT → TPS enabled → device ON)

2. LED2 (red 0603): power indicator, always on via 3V3→R12→LED2→GND
   R12 (1k 0402): current limiter for LED2

3. LED3 (green 0603): WiFi/success status, GPIO-driven via U1.36→R13→LED3→GND
   R13 (1k 0402): current limiter for LED3

4. Silkscreen cleanup: uniform text size, move refs off pads

5. Update U2.3 net: VBAT → TPS_EN (new net)
   Update U1.36: unassigned → LED_WIFI (new net)
"""
from pathlib import Path
import pcbnew

ROOT = Path(__file__).resolve().parents[1]
BOARD = ROOT / "device_kicad" / "CameraIoT_38x18_routed.kicad_pcb"


def mm(v):
    return pcbnew.FromMM(v)


def add_net(b, name):
    existing = b.FindNet(name)
    if existing and existing.GetNetCode() > 0:
        return existing
    ni = pcbnew.NETINFO_ITEM(b, name)
    b.Add(ni)
    return b.FindNet(name)


def clone_fp(b, src_ref, new_ref, new_val, x, y, pad_nets, orientation=0):
    """Clone existing footprint, relocate, rename, reassign nets."""
    src = next(f for f in b.GetFootprints() if f.GetReference() == src_ref)
    clone = pcbnew.Cast_to_FOOTPRINT(src.Duplicate(False))
    clone.SetReference(new_ref)
    clone.SetValue(new_val)
    clone.SetPosition(pcbnew.VECTOR2I(mm(x), mm(y)))
    clone.SetOrientationDegrees(orientation)
    for pad in clone.Pads():
        pn = pad.GetNumber()
        if pn in pad_nets:
            net = b.FindNet(pad_nets[pn])
            if net and net.GetNetCode() > 0:
                pad.SetNet(net)
    b.Add(clone)
    return clone


def create_switch_fp(b, ref, val, cx, cy, net_gnd, net_com, net_vbat):
    """
    Create 3-pad SMD slide switch footprint (MSK-12C02 / SS-12D00 compatible).
    Pads in a row with 2.0mm pitch:
      pad1 = net_gnd  (left,  OFF position)
      pad2 = net_com  (center, COM)
      pad3 = net_vbat (right, ON position)
    """
    fp = pcbnew.FOOTPRINT(b)
    fp.SetReference(ref)
    fp.SetValue(val)
    fp.SetPosition(pcbnew.VECTOR2I(mm(cx), mm(cy)))
    fp.SetLayer(pcbnew.F_Cu)

    # Reference text
    fp.Reference().SetTextSize(pcbnew.VECTOR2I(mm(0.4), mm(0.4)))
    fp.Reference().SetTextThickness(mm(0.06))
    fp.Reference().SetPosition(pcbnew.VECTOR2I(mm(cx), mm(cy - 1.8)))
    fp.Reference().SetLayer(pcbnew.F_SilkS)

    # Value text
    fp.Value().SetTextSize(pcbnew.VECTOR2I(mm(0.4), mm(0.4)))
    fp.Value().SetTextThickness(mm(0.06))
    fp.Value().SetPosition(pcbnew.VECTOR2I(mm(cx), mm(cy + 1.8)))
    fp.Value().SetLayer(pcbnew.F_Fab)

    pad_defs = [
        ("1", -2.0, net_gnd),
        ("2",  0.0, net_com),
        ("3", +2.0, net_vbat),
    ]
    ls = pcbnew.LSET()
    ls.AddLayer(pcbnew.F_Cu)
    ls.AddLayer(pcbnew.F_Paste)
    ls.AddLayer(pcbnew.F_Mask)

    for num, x_off, net_name in pad_defs:
        pad = pcbnew.PAD(fp)
        pad.SetNumber(num)
        pad.SetShape(pcbnew.PAD_SHAPE_RECT)
        pad.SetAttribute(pcbnew.PAD_ATTRIB_SMD)
        pad.SetLayerSet(ls)
        pad.SetSize(pcbnew.VECTOR2I(mm(1.5), mm(1.5)))
        pad.SetPosition(pcbnew.VECTOR2I(mm(cx + x_off), mm(cy)))
        net = b.FindNet(net_name)
        if net and net.GetNetCode() > 0:
            pad.SetNet(net)
        fp.Add(pad)

    b.Add(fp)
    return fp


def fix_silkscreen(b):
    """Move all reference texts to clear position above the component bbox."""
    for fp in b.GetFootprints():
        ref = fp.GetReference()
        # Skip test pads and mounting holes
        if ref.startswith("TP") or ref.startswith("MH") or ref.startswith("BAT"):
            fp.Reference().SetVisible(False)
            continue

        ref_t = fp.Reference()
        ref_t.SetTextSize(pcbnew.VECTOR2I(mm(0.4), mm(0.4)))
        ref_t.SetTextThickness(mm(0.06))

        # Place reference above component centroid
        cx = pcbnew.ToMM(fp.GetPosition().x)
        cy = pcbnew.ToMM(fp.GetPosition().y)
        ref_t.SetPosition(pcbnew.VECTOR2I(mm(cx), mm(cy - 1.0)))
        ref_t.SetLayer(pcbnew.F_SilkS)
        ref_t.SetMirrored(False)


def add_short_trace(b, net_name, layer, x1, y1, x2, y2, width=0.15):
    """Add a copper trace segment."""
    net = b.FindNet(net_name)
    if not net or net.GetNetCode() <= 0:
        print(f"  WARNING: net '{net_name}' not found for trace")
        return
    seg = pcbnew.PCB_TRACK(b)
    seg.SetNet(net)
    seg.SetLayer(layer)
    seg.SetStart(pcbnew.VECTOR2I(mm(x1), mm(y1)))
    seg.SetEnd(pcbnew.VECTOR2I(mm(x2), mm(y2)))
    seg.SetWidth(mm(width))
    b.Add(seg)
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

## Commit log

2026-06-19 Initial commit: Camera IoT hardware design, firmware, and documentation
    [CameraIoT_38x18_BOM_JLCPCB.csv, CameraIoT_38x18_FINAL.kicad_pcb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]
2026-06-19 Replace repository contents
    [CameraIoT_38x18_BOM_JLCPCB.csv, CameraIoT_38x18_FINAL.kicad_pcb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]
2026-06-19 include pico-cam-latest contents
    [CameraIoT_38x18_BOM_JLCPCB.csv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]
